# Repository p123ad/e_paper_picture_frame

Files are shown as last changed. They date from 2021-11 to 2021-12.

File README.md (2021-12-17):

# Battery Operated E-Paper Picture Frame

## Table of Contents

- [About](#about)
- [Getting Started](#getting_started)
- [BOM](#bom)
- [Printed Parts](#printed_parts)
- [Mechanical Build](#mechanics)
- [Electrical Build](#electronics)
- [Preparing the pictures](#pictures)
- [Code](#code)
- [Ressources](#ressources)

## About 

This is a project creating a battery operated digital picture frame. I hated the hassel with commercial digital picture frames which are only showing pictures while connectd to mains. So it was down for most of the time showing a black screen.
My goal was to design a concept for a digital picture frame with very low power consumption. So the choice fell towards a esp32 board with a very low deep sleep current, together with a low power E-paper display, which only consumes power during picture change.

<p align="center">
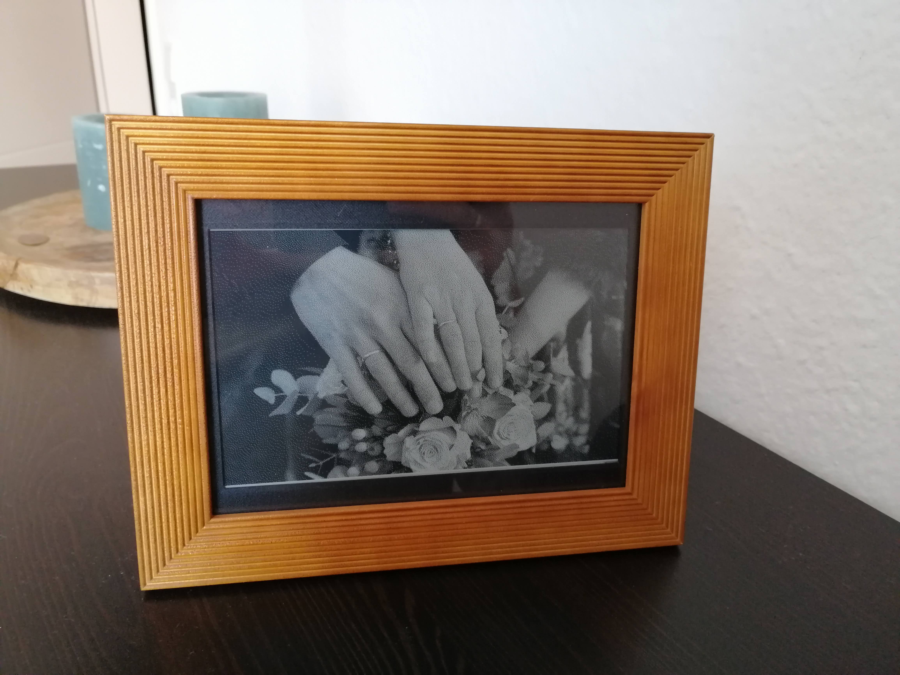
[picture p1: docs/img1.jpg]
  
</p>

The Firebeetle ESP32 has a deep sleep current of only 0.053mA according to great research of [The guy with the swiss accent](https://docs.google.com/spreadsheets/d/1Mu-bNwpnkiNUiM7f2dx8-gPnIAFMibsC2hMlWhIHbPQ/edit#gid=0)

# Build Instruction 

For this build you have to source some parts and 3d print some.

## BOM 

| Count | Part  | Cost  |
|---|---|---|
| 1 | [E-Paper Display](https://www.waveshare.com/7.5inch-hd-e-paper-hat.htm)  | 60.99$  |
| 1 | [Picture Frame](https://www.nanu-nana.de/bilderrahmen-classic-15-x-20-cm-eiche-2002262014571/)  |  4.95€ |
| 1 |  [LiPo 3.7V](https://www.welectron.com/LiPo-Flachakku-503562-37V-1200mAh)  | 5.50€  |
| 1 | [Firebeetle ESP32](https://www.dfrobot.com/product-1590.html) | 6.90$ |
| 1 | Brass Screw | ~ 1€ |
| 4 | M2x4mm Screws |  |
| 4 | M2x8mm Screws |  |
| 8 | [M2 Threaded Inserts](https://www.amazon.de/gp/product/B08K1BVGN9/ref=ppx_yo_dt_b_asin_title_o04_s00?ie=UTF8&th=1) |  |

## Printed Parts 

I printed the parts in wooden PLA filament on my Prusa Mini.

| Count | Part |
| --- | --- |
| 1 | Back |
| 1 | Passepartout |
| 2 | Stand |
| 1 | Lid |

## Mechanical Build 

First solder a wire together with the brass screw. This can be very tricky because of the high temperature needed.
If you struggle, an idea is to drill a 1.5-2.0mm hole into the screw. Add solder to the hole and heat it up so you can put the wire into the hole with the hot solder.
Drill a hole with a 4.5mm drill bit into the frame where you want to place the button-screw.

<p align="center">
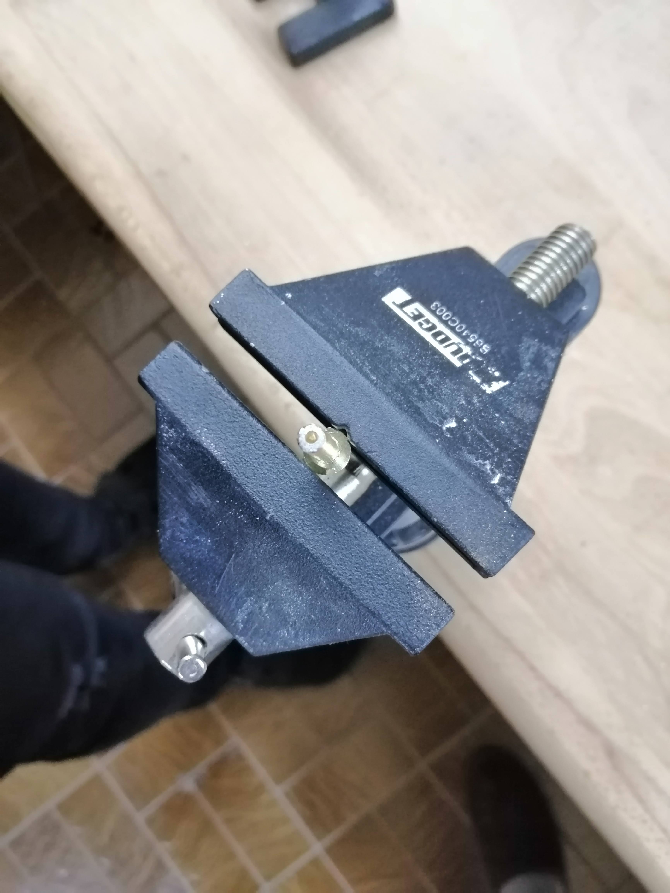
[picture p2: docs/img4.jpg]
  
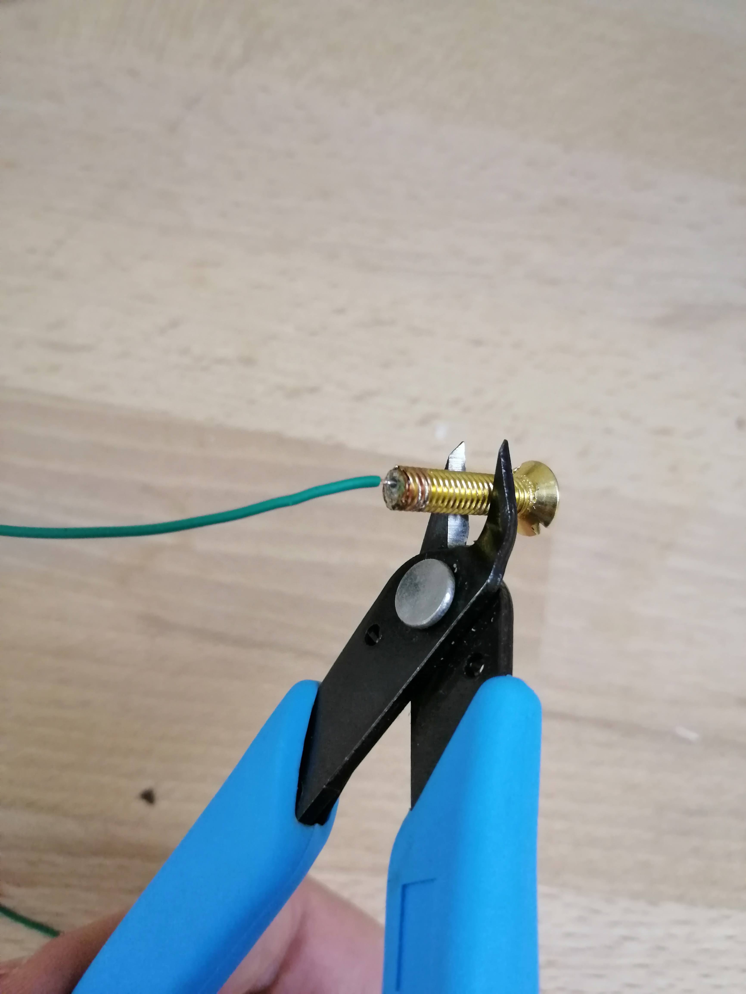
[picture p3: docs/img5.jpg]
  
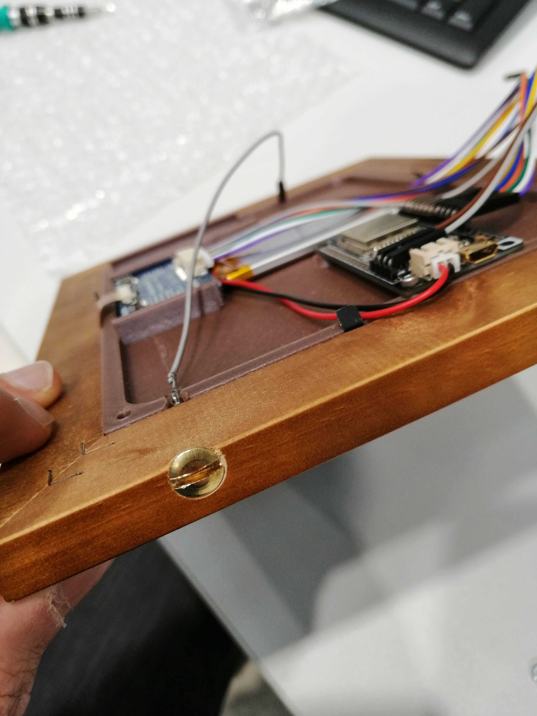
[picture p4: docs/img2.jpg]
  
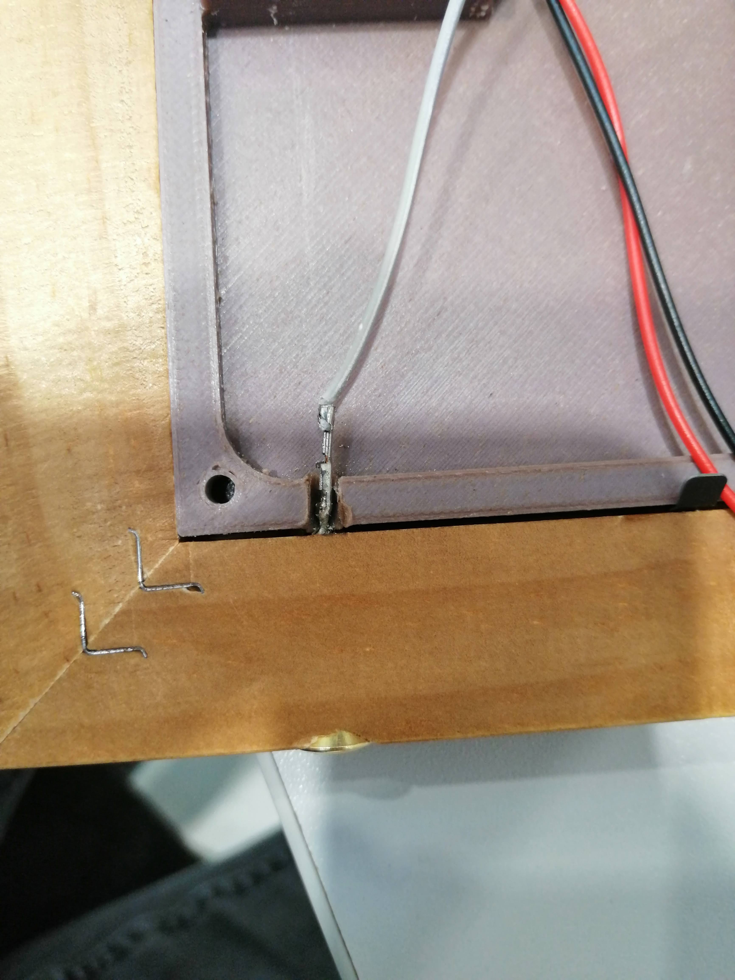
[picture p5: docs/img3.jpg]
  
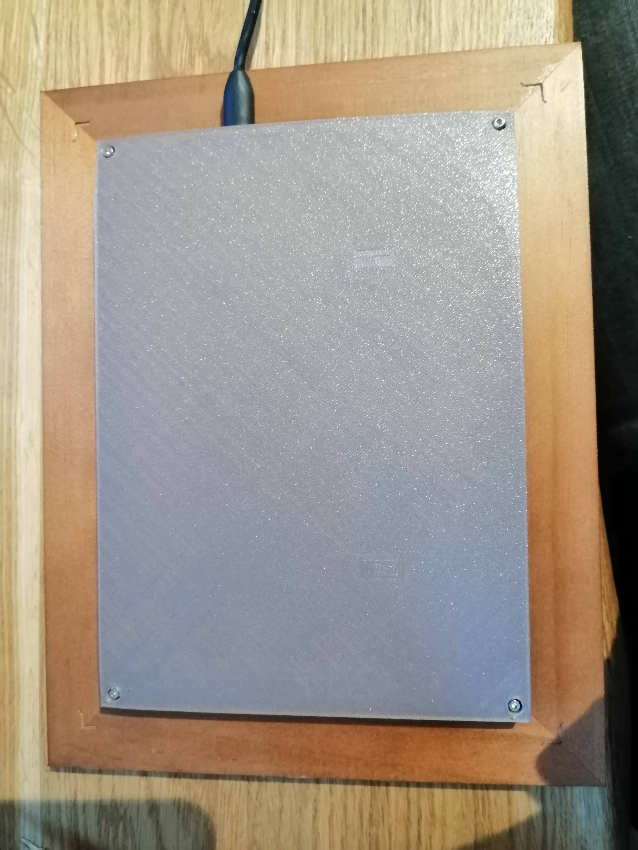
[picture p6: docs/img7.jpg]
  
</p>

## Electrical Build 

Connect the ESP board according to the wiring sketch.

<p align="center">
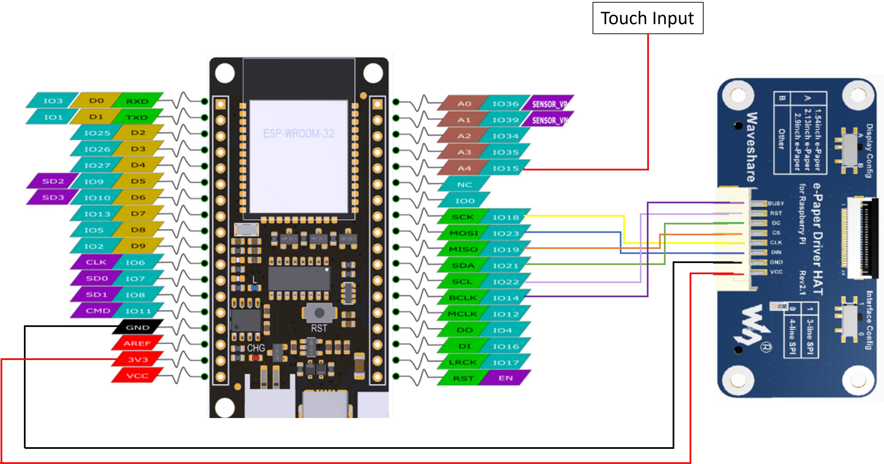
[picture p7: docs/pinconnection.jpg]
  
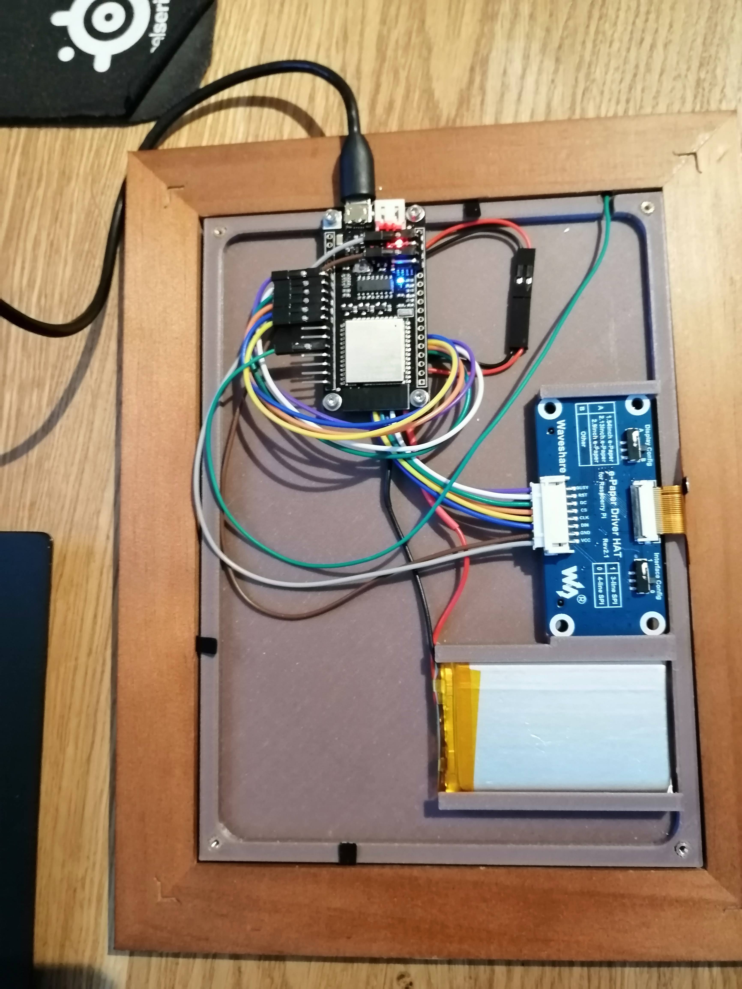
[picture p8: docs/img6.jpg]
  
</p>

## Preparing the Pictures 

Since the E-paper Display only allows Pictures with a resolution of 880x528px with only black and white pixels you have to edit your pictures according these constraints. You find a reference from waveshare [here](https://www.waveshare.com/wiki/E-Paper_Floyd-Steinberg)
I will give a short step-by-step instruction of the process, which worked for me.

1. Install [GIMP](https://www.gimp.org/)
2. Open GIMP
3. Drag and Drop a Picture (.jpg) into the GIMP Workspace
4. Layer -> Scale layer... → set to 880px
5. Layer -> Scale Height.. -> set to 528px
6. Image → Crop to content
7. Colors → Desaturate → Desaturate ...
8. Colors → Posterize → 16 levels (optional)
9. Image → Mode → Indexed ... → Use black/white palette (1-bit)
10. Dithering → Color dithering: Floyd-Steinberg (normal) → Convert
11. File → Export to ... → Append .bmp extension → Export
12. Use [this tool](https://javl.github.io/image2cpp/) to convert your .bmp files to cpp byte code. Set the code output mode to Arduino Code
13. Copy the byte code to your Arduino project

## Code 

Open the main.ino file with your Arduino IDE. There should be a few tabs. Each picture has to prepared according to the example picture in a `.c` and a `.h` file. Then the include path has to be added to `Picutes.h`.
Please also look through the `main.ino` file and change the code according to the names and numers of your pictures.

## Ressources 

There are many ohter cool e-paper based picture frame projects out there which have many other special features. My work was also inspired by them. But my focus was to build a very low power consuming project to have it battery operated.

1. [E-Paper Picture that changes for my Mother](https://www.youtube.com/watch?v=YawP9RjPcJA)
2. [E-Ink Photo Frame using Raspberry Pi](https://www.youtube.com/watch?v=K_ueApCixTA)
3. [ESP32 E-Paper Frame](https://github.com/dani3lwinter/ESP32_ePaper_Frame)

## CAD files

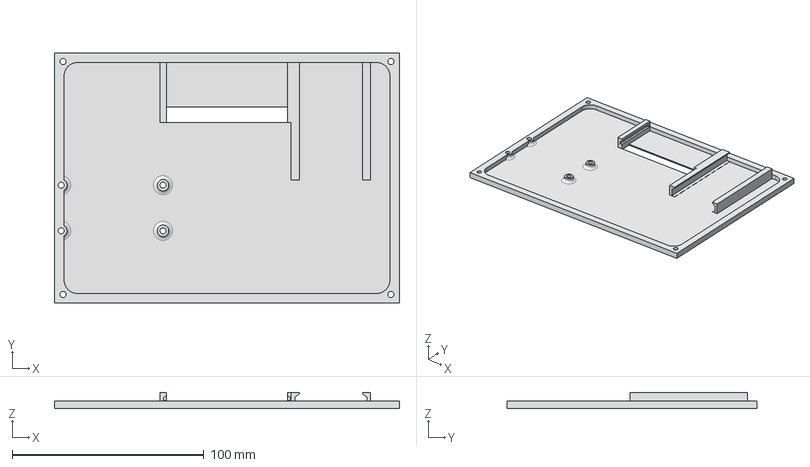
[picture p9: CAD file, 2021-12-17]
cad/Back Cover v5.stp
180.0 x 130.5 x 8.45 mm

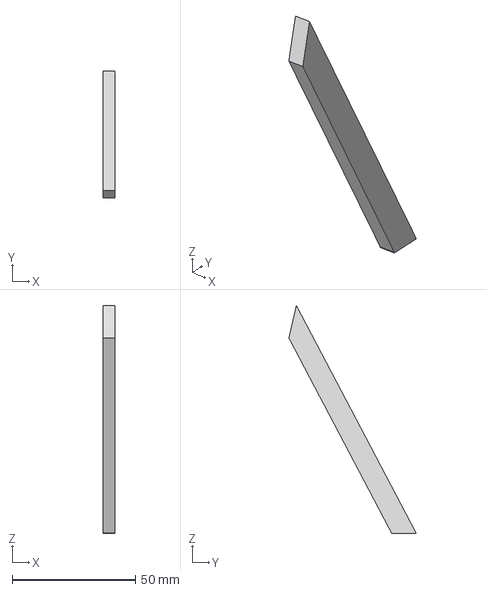
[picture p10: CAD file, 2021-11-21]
cad/Stand.stp
5.00 x 51.7 x 92.6 mm

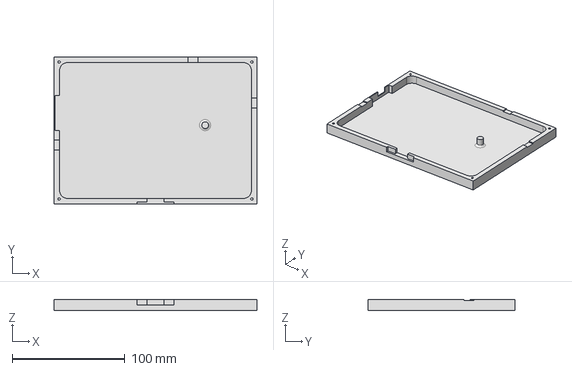
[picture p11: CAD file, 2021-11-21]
cad/Lid.stp
180.0 x 130.5 x 10.0 mm

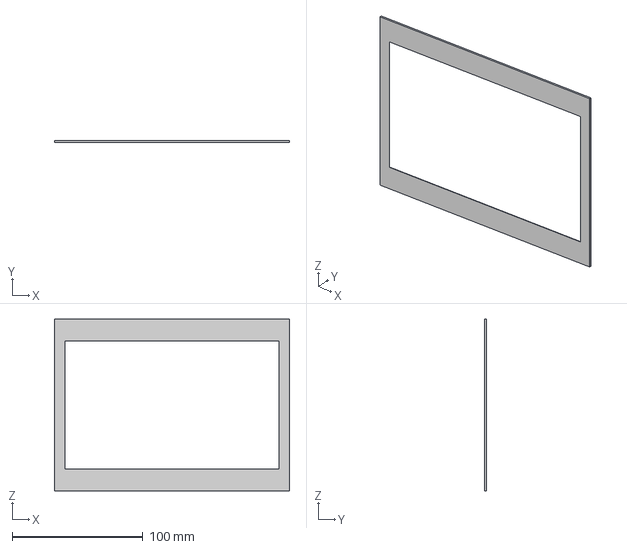
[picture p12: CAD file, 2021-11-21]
cad/Passepartout.step
180.0 x 1.40 x 131.5 mm

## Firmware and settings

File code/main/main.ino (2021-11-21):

/**
notes: 
  - Some very short delays have been inserted because Serial Monitor sometimes didn't showed complete messages
**/

#include "Pictures.h"
#include "epaper.h"
#include "deepSleep.h"

#define uS_TO_S_FACTOR 1000000ULL  /* Conversion factor for micro seconds to seconds */
#define TIME_TO_SLEEP  24*60*60        /* ESP32 will go to sleep for 24 hours (in seconds) */


#define Threshold 40 /* Greater the value, more the wakeup sensitivity of touch wakeup */
RTC_DATA_ATTR int bootCount = 0; //store a value on RTC Memory, data is not erased during deep sleep
RTC_DATA_ATTR int nextPic=0; 

void callback(){
  //placeholder callback function
}

void showNewSequenceImage(){
  //initialize communication and save memory for image buffer 
  initializePaperDisplay();
  delay(10);
  
  switch(nextPic){

    case 0  :   displayPicture(myPic1); Serial.println("Show Pic1"); break;
    case 1  :   displayPicture(myPic2); Serial.println("Show Pic2"); break;
    case 2  :   displayPicture(myPic3); Serial.println("Show Pic3"); break;
    case 3  :   displayPicture(myPic4); Serial.println("Show Pic4"); break;
    case 4  :   displayPicture(myPic5); Serial.println("Show Pic5"); break;
    case 5  :   displayPicture(myPic6); Serial.println("Show Pic6"); break;
    case 6  :   displayPicture(myPic7); Serial.println("Show Pic7"); break;
    case 7  :   displayPicture(myPic8); Serial.println("Show Pic8"); break;
    case 8  :   displayPicture(myPic9); Serial.println("Show Pic9"); break;
    case 9  :   displayPicture(myPic10); Serial.println("Show Pic10"); break;
    case 10  :   displayPicture(myPic11); Serial.println("Show Pic11"); break;
    case 11  :   displayPicture(myPic12); Serial.println("Show Pic12"); break;
    case 12  :   displayPicture(myPic13); Serial.println("Show Pic13"); break;
    case 13  :   displayPicture(myPic14); Serial.println("Show Pic14"); break;
    case 14  :   displayPicture(myPic15); Serial.println("Show Pic15"); break;
    case 15  :   displayPicture(myPic16); Serial.println("Show Pic16"); break;
    case 16  :   displayPicture(myPic17); Serial.println("Show Pic17"); break;
  }

  nextPic++;

  if(nextPic > 13)
    nextPic = 0;

}


void showNewRandomImage(){
  //initialize communication and save memory for image buffer 
  initializePaperDisplay();
  delay(10);

  //Generate random image number
  int picNumber = random(14);

  //display the random image 
  switch(picNumber){
    case 0  :   displayPicture(myPic1); Serial.println("Show Pic1"); break;
    case 1  :   displayPicture(myPic2); Serial.println("Show Pic2"); break;
    case 2  :   displayPicture(myPic3); Serial.println("Show Pic3"); break;
    case 3  :   displayPicture(myPic4); Serial.println("Show Pic4"); break;
    case 4  :   displayPicture(myPic5); Serial.println("Show Pic5"); break;
    case 5  :   displayPicture(myPic6); Serial.println("Show Pic6"); break;
    case 6  :   displayPicture(myPic7); Serial.println("Show Pic7"); break;
    case 7  :   displayPicture(myPic8); Serial.println("Show Pic8"); break;
    case 8  :   displayPicture(myPic9); Serial.println("Show Pic9"); break;
    case 9  :   displayPicture(myPic10); Serial.println("Show Pic10"); break;
    case 10  :   displayPicture(myPic11); Serial.println("Show Pic11"); break;
    case 11  :   displayPicture(myPic12); Serial.println("Show Pic12"); break;
    case 12  :   displayPicture(myPic13); Serial.println("Show Pic13"); break;
    case 13  :   displayPicture(myPic14); Serial.println("Show Pic14"); break;
    case 14  :   displayPicture(myPic15); Serial.println("Show Pic15"); break;
    case 15  :   displayPicture(myPic16); Serial.println("Show Pic16"); break;
    case 16  :   displayPicture(myPic17); Serial.println("Show Pic17"); break;
  }
  //now clear memory and set display in sleep mode
  sleepPaperDisplay();
}

void setup() {
  Serial.begin(115200);
  delay(1000); //Take some time to open up the Serial Monitor

  //Increment boot number and print it every reboot
  ++bootCount;
  Serial.println("Boot number: " + String(bootCount));
  delay(10);

  //Print the wakeup reason for ESP32 and touchpad too
  print_wakeup_reason();
  print_wakeup_touchpad();
  delay(10);

  //print new picture to the Display
  showNewSequenceImage();


  //Setup interrupt on Touch Pad 3 (A4 / GPIO15)
  touchAttachInterrupt(T3, callback, Threshold);

  //Configure Touchpad as wakeup source
  esp_sleep_enable_touchpad_wakeup();

  //Configure Timer as wakeup source too
  esp_sleep_enable_timer_wakeup(TIME_TO_SLEEP * uS_TO_S_FACTOR); //accepts a uint64_t value (range: 2^64 − 1 which equals 18.446.744.073.709.551.615)
  Serial.println("Setup ESP32 to sleep for every " + String(TIME_TO_SLEEP) + " Seconds");
  delay(10);


  //Go to sleep now
  Serial.println("Going to sleep now...");
  Serial.flush(); //Waits for the transmission of outgoing serial data to complete
  esp_deep_sleep_start();
  Serial.println("This will never be printed");

}

/* The main loop -------------------------------------------------------------*/
void loop()
{
  //
}

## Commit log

2021-11-21 add all files
    [Back.ipt, Passepartout.step, Stand.stp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]
2021-11-21 update files and Readme
    [Lid.stp, Stand.stp, Stelze.stp]
2021-12-17 add back step file
    [Back Cover v5.stp, Back.ipt]
